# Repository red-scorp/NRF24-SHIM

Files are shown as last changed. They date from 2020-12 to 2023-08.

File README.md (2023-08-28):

# NRF24-SHIM project

NRF24-SHIM (mini-HAT), an interface board for NRF32L01+ radio boards for Raspberry Pi.

This project came to reality when I was looking for a way to connect standard NRF24L01+ module to my Pi.
I had found many tutorials explaining how to connect NRF24 modules to Pi but no ready made board or even proper schematics.
"Hmm... DIY!" I've told myself and here we are.

## NRF24-SHIM

Raspberry Pi 40-pin **NRF24-SHIM** mini-HAT.

Preview:

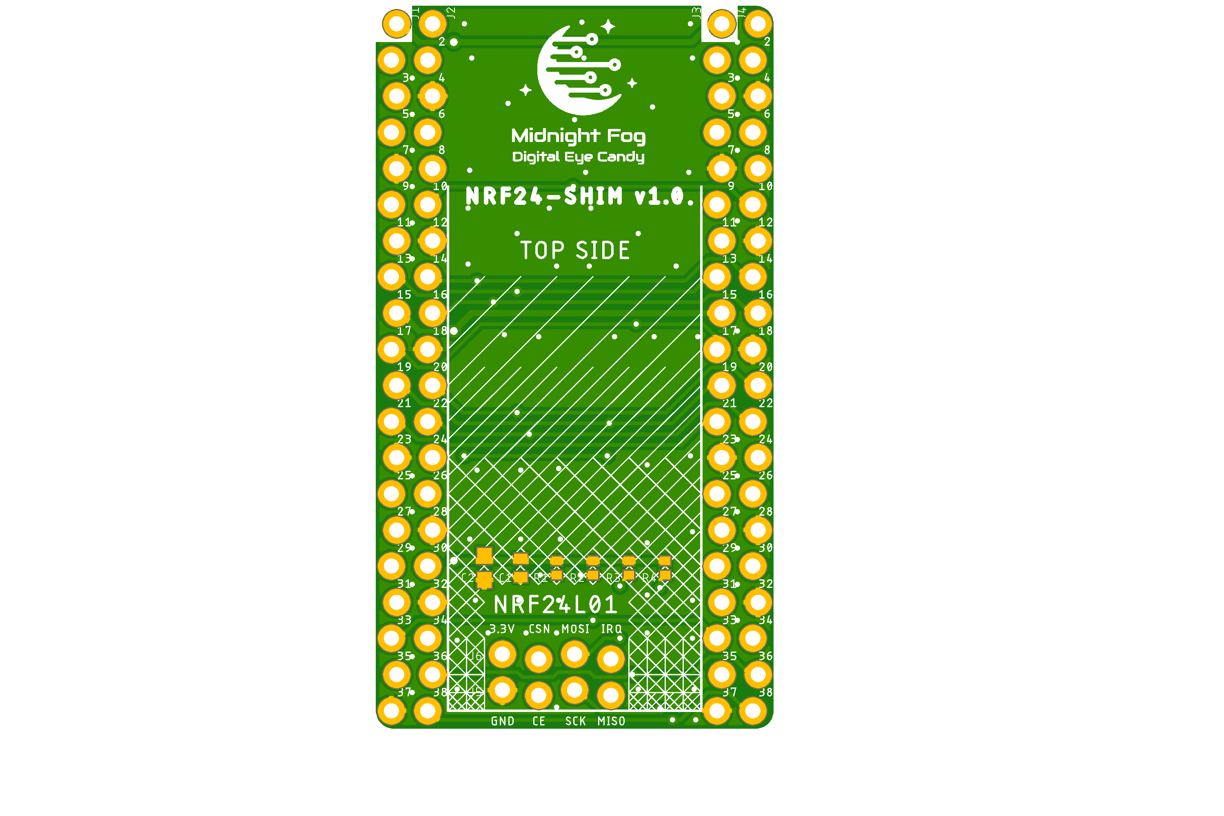
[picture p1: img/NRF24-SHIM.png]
NRF24-SHIM preview


[Schematics in PDF format](doc/NRF24-SHIM.pdf)

Features:

- locked Pi headers
- locked NRF24 headers
- double set of Pi headers (for inside and outside mount)
- SPI0/SPI1 bus selection
- CE/IRQ selection
- can be used as SHIM (no headers) or HAT (with headers)

Pins Configuration:

|NRF24 Pin |Option 1 |Option 2 |
|---|---|---|
|CE |GPIO22\* |GPIO25 |
|CSN |GPIO8\*  |GPIO18 |
|SCK |GPIO11\* |GPIO21 |
|MOSI |GPIO10\* |GPIO20 |
|MISO |GPIO9\*  |GPIO19 |
|IRQ |GPIO23 |GPIO24 |

\*) the pin is connected by default.

CAM files are available.

## NRF24-mini-SHIM

Raspberry Pi **NTF32-mini-SHIM** micro-HAT.

Preview:

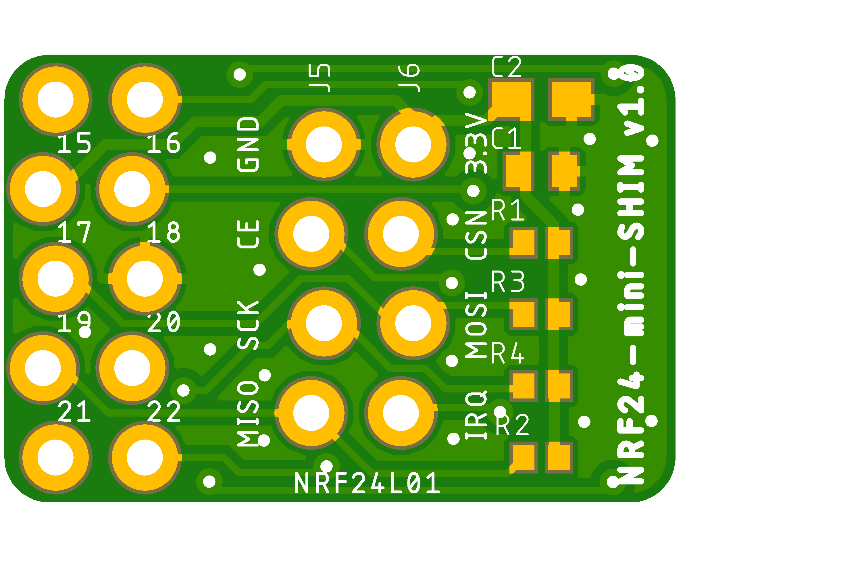
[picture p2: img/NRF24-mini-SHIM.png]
NRF24-mini-SHIM preview


[Schematics in PDF format](doc/NRF24-mini-SHIM.pdf)

Features:

- locked Pi headers
- locked NRF24 headers
- CE/IRQ selection
- very small size
- fits on 26- and 40-pin Pi headers

Pins Configuration:

|NRF24 Pin |Option 1 |Option 2 |
|---|---|---|
|CE |GPIO22\* |GPIO25 |
|CSN |GPIO8\*  | |
|SCK |GPIO11\* | |
|MOSI |GPIO10\* | |
|MISO |GPIO9\*  | |
|IRQ |GPIO23 |GPIO24 |

\*) the pin is connected by default.

CAM files are available.

## NRF24-zero-SHIM

Raspberry Pi zero 40-pin **NRF24-zero-SHIM** mini-HAT.

Preview:

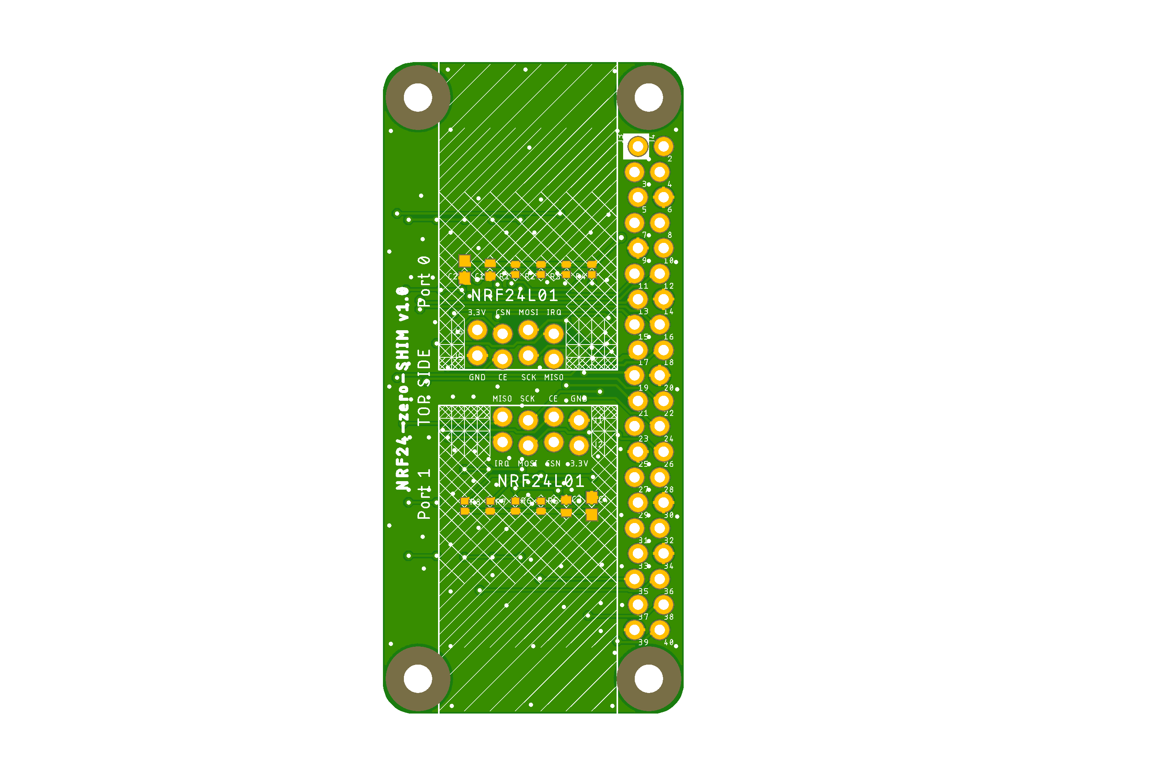
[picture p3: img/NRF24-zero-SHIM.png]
NRF24-zero-SHIM preview


[Schematics in PDF format](doc/NRF24-zero-SHIM.pdf)

Features:

- locked Pi headers
- locked NRF24 headers
- Pi zero board style
- SPI0/SPI1 bus selection
- CE/IRQ selection
- double NRF24 configuration possible
- can be used as SHIM (no headers) or HAT (with headers)

Pins Configuration:

|NRF24 Pin |Option 1 |Option 2 |Option 3 |Option 4 |Option 5 |
|---|---|---|---|---|---|
|P0 CE |GPIO22\* |GPIO25 |GPIO27 | | |
|P0 CSN |GPIO8\*  |GPIO7 |GPIO18 |GPIO17 |GPIO16 |
|P0 SCK |GPIO11\* |GPIO21 | | | |
|P0 MOSI |GPIO10\* |GPIO20 | | | |
|P0 MISO |GPIO9\*  |GPIO19 | | | |
|P0 IRQ |GPIO23 |GPIO24 | | | |
|P1 CE |GPIO22 |GPIO25\* |GPIO27 | | |
|P1 CSN |GPIO8 |GPIO7 |GPIO18\* |GPIO17 |GPIO16 |
|P1 SCK |GPIO11 |GPIO21\* | | | |
|P1 MOSI |GPIO10 |GPIO20\* | | | |
|P1 MISO |GPIO9 |GPIO19\* | | | |
|P1 IRQ |GPIO23 |GPIO24 | | | |

\*) the pin is connected by default.

CAM files are available.

## BOM

Bill Of Materials is currently available only for LCSC Electronic Components Distributor, which is probably cheapest anyway.

### LCSC BOM

|Designator |Part/Value |Package/Footprint |LCSC # |
|---|---|---|---|
|C1, C3\* |Cap. 100nF |0402 |C1525  |
|C2, C4\* |Cap. 1uF |0603 |C15849 |
|R1, R2, R3, R4, R5, R6, R7, R8\*|Res. 10K |0402 |C25744 |

\*) These passive components are optional but it's recommended to install them.

## Links

- [pinout.xyz](https://pinout.xyz/) - a brilliant resource on topic of Pi's pinout and HATs.
- [raspberrypi/hats](https://github.com/raspberrypi/hats) - Pi's HAT specification.
- [Communication between Arduino AND Raspberry Pi using NRF24L01](https://medium.com/@anujdev11/communication-between-arduino-and-raspberry-pi-using-nrf24l01-818687f7f363) - how to setup NRF24L01 with Pi.
- [Funkkommunikation zwischen Raspberry Pi’s und Arduinos (2.4 GHz)](https://tutorials-raspberrypi.de/funkkommunikation-zwischen-raspberry-pis-und-arduinos-2-4-ghz/) - how to setup NRF24L01 with Pi in German.
- [Connecting an nRF24L01+ to Raspberry Pi](https://www.hackster.io/wirekraken/connecting-an-nrf24l01-to-raspberry-pi-9c0a57) - one more setup example.

## How to help

Your contributions as code, resources, or finances are welcome! Please contact me directly via email at andriy.golovnya@gmail.com or through my [GitHub profile](https://github.com/red-scorp).

If you'd like to make a financial contribution, you can donate via [PayPal](http://paypal.me/redscorp) or [Ko-Fi](http://ko-fi.com/redscorp). Your support is greatly appreciated.

Thanks in advance!

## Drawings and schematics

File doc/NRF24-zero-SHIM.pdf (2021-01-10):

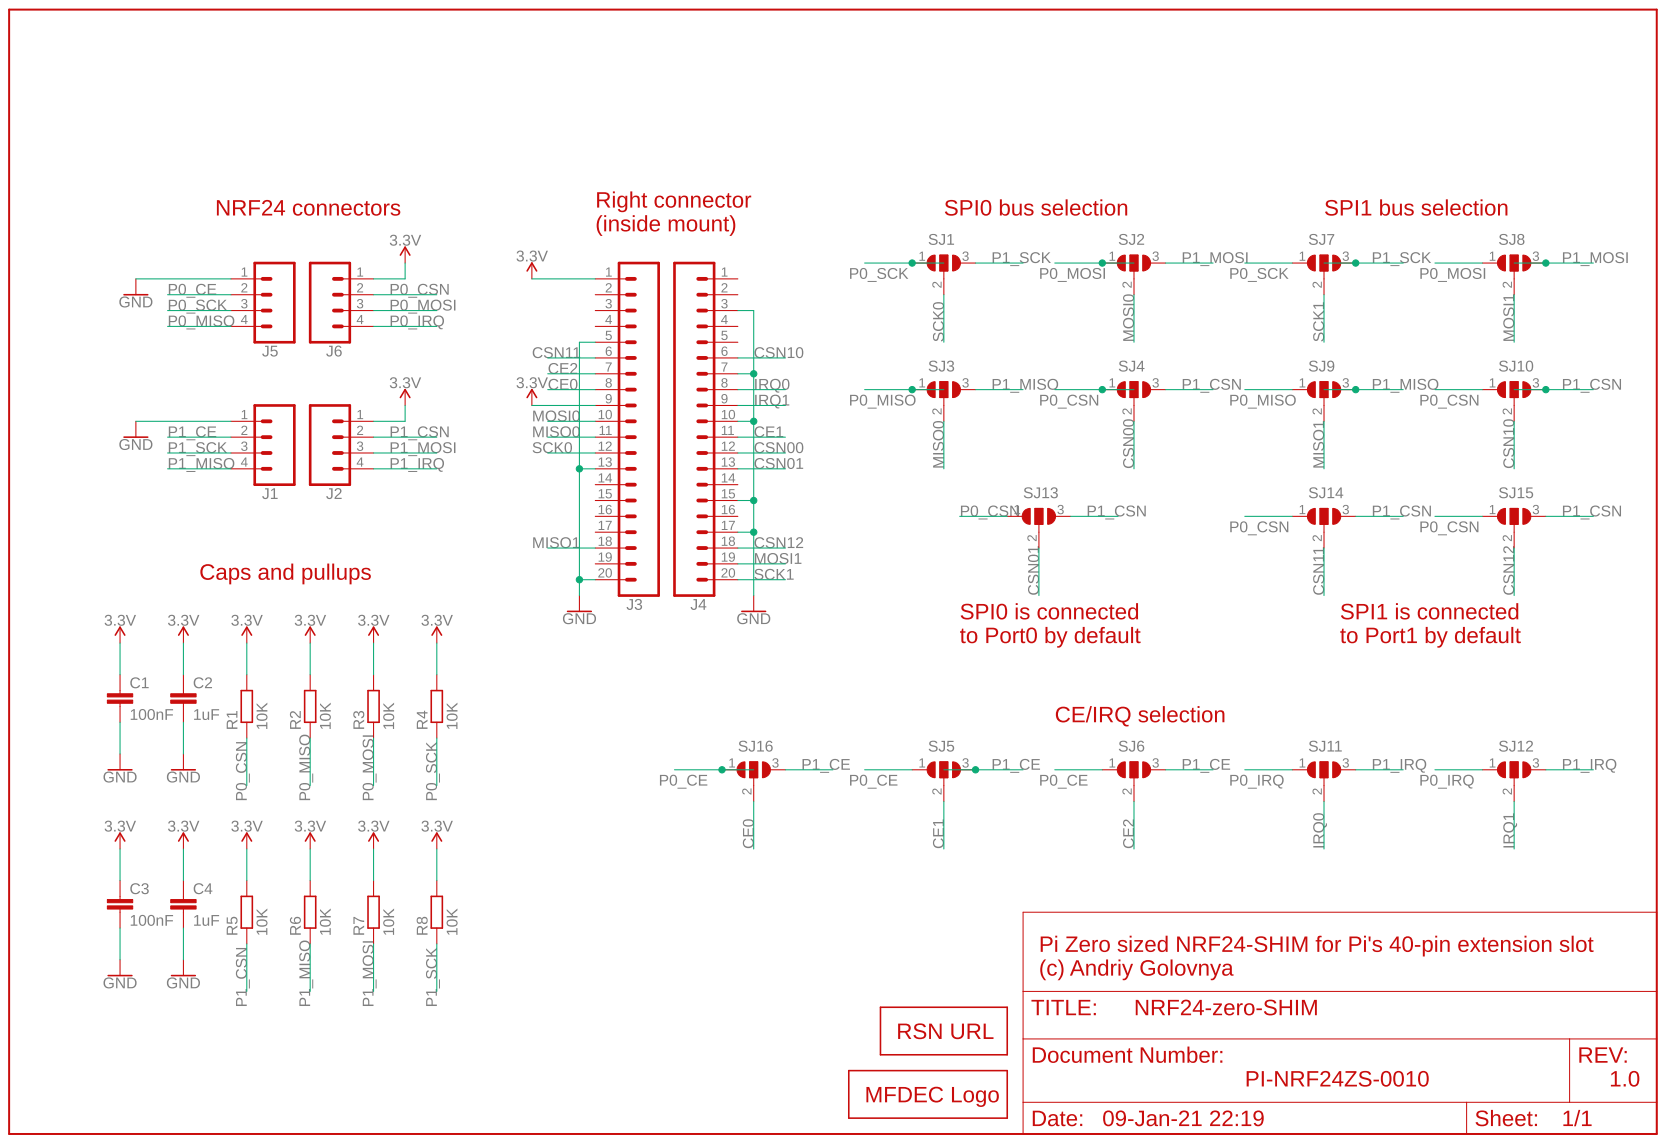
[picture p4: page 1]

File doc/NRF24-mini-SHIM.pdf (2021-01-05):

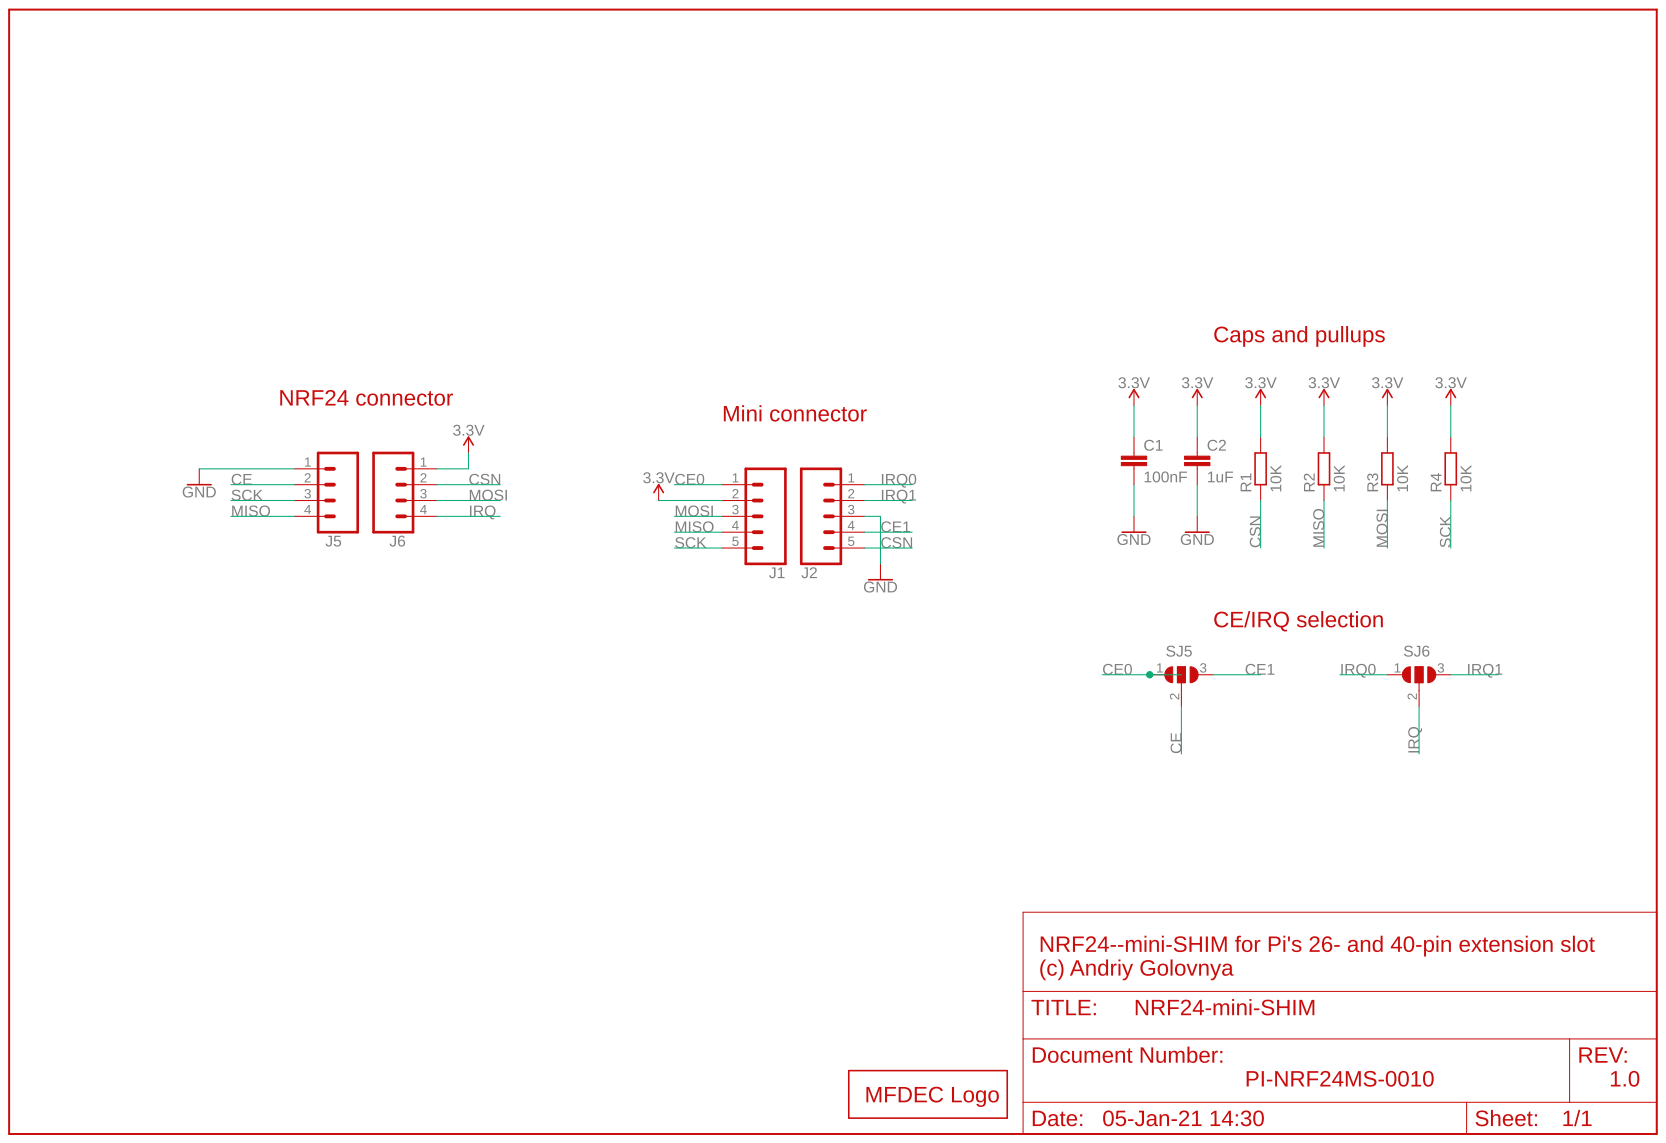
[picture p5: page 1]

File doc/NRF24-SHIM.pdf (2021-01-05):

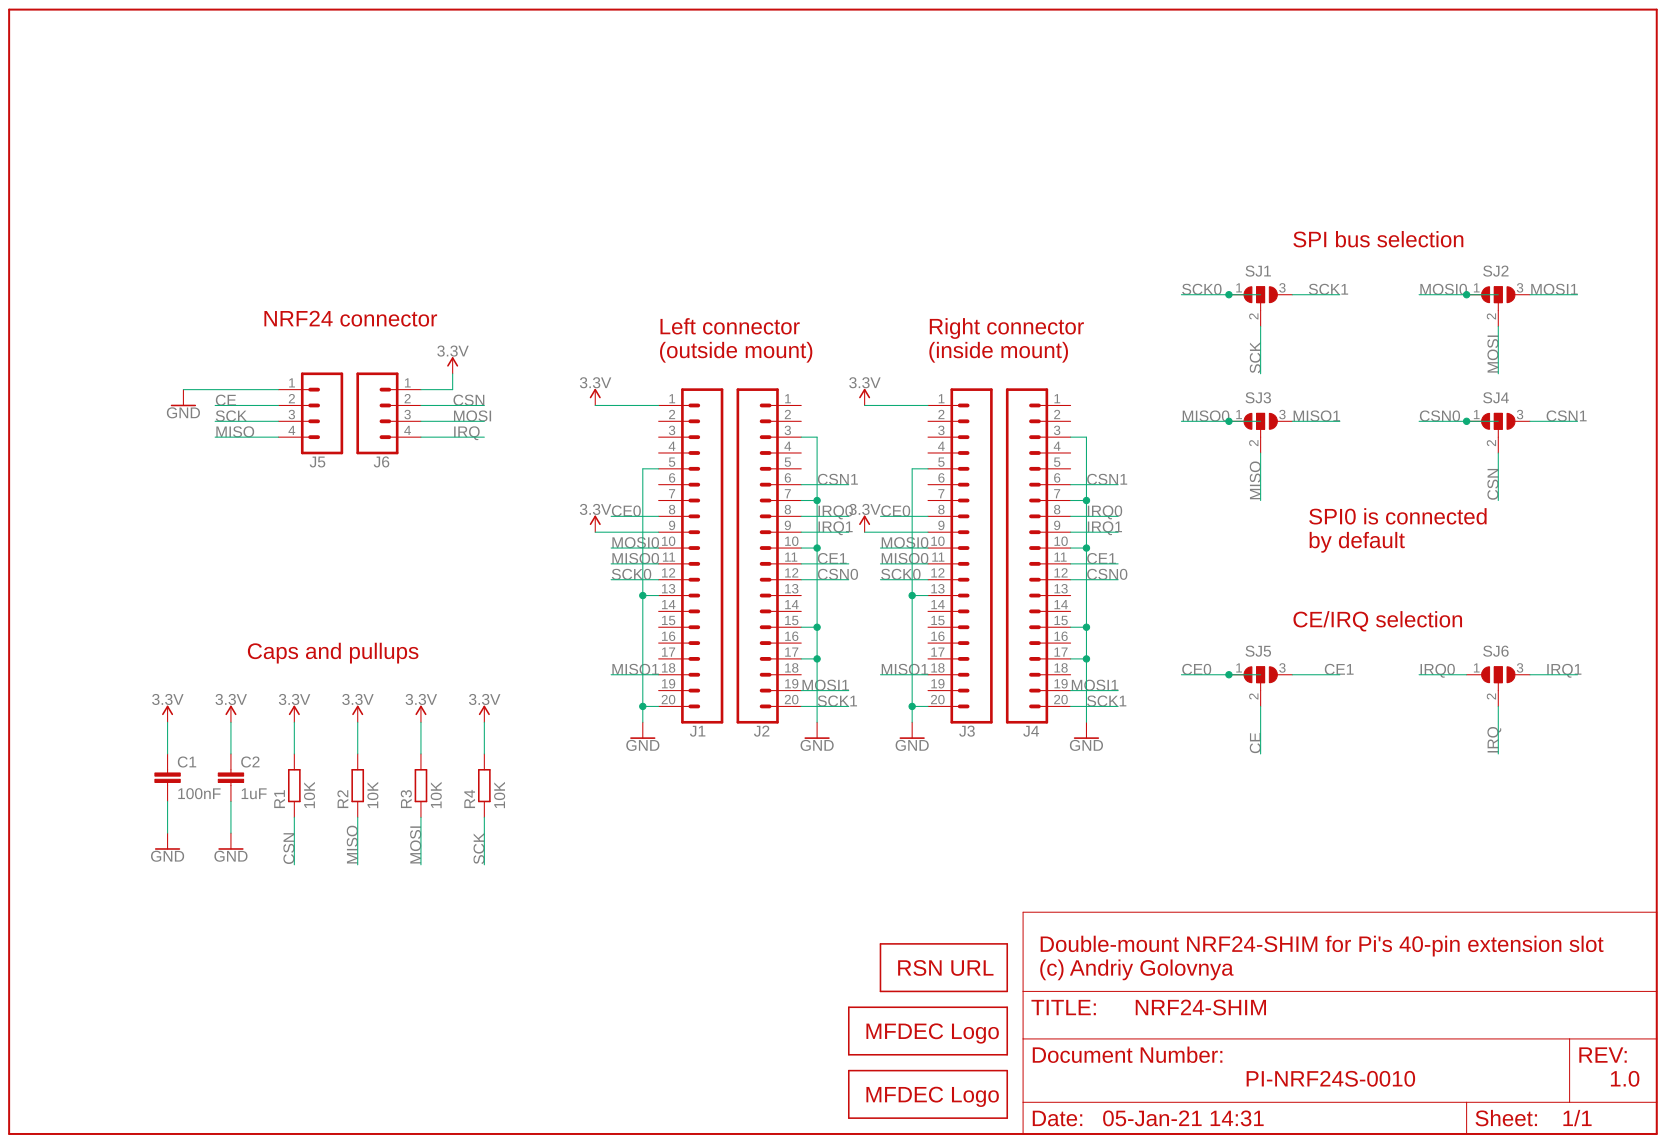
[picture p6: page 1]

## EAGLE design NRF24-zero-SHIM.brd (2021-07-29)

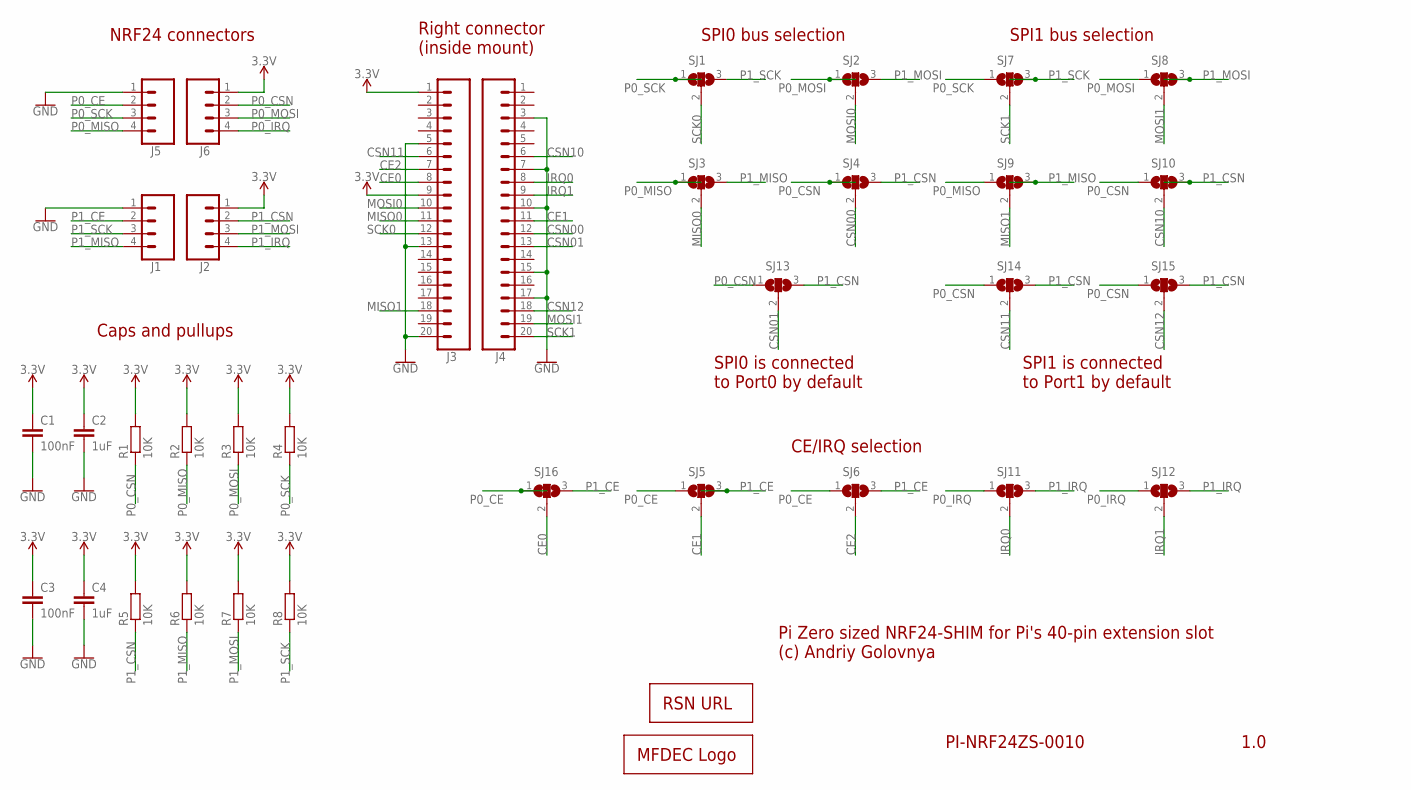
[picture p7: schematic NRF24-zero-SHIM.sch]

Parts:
C1, C3: 100nF; C0402
C2, C4: 1uF; C0603
J1, J2, J5, J6: CONN_04LOCK; 1X04_LOCK
J3, J4: CONN_20LOCK; 1X20_LOCK
LOGO1: MFDECLOGO_SQ_8MM; MFDEC_SQ_8MM
LOGO3: RSNURL_QR_10MM
R1, R2, R3, R4, R5, R6, R7, R8: 10K; R0402
SJ1, SJ2, SJ3, SJ4, SJ5, SJ6, SJ7, SJ8, SJ9, SJ10, SJ11, SJ12, SJ13, SJ14, SJ15, SJ16: SJ2; SJ_2

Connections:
3.3V: C1.1, C2.1, C3.1, C4.1, J2.1, J3.1, J3.9, J6.1, R1.2, R2.2, R3.2, R4.2, R5.2, R6.2, R7.2, R8.2
CE0: J3.8, SJ16.2
CE1: J4.11, SJ5.2
CE2: J3.7, SJ6.2
CSN00: J4.12, SJ4.2
CSN01: J4.13, SJ13.2
CSN10: J4.6, SJ10.2
CSN11: J3.6, SJ14.2
CSN12: J4.18, SJ15.2
GND: C1.2, C2.2, C3.2, C4.2, J1.1, J3.5, J3.13, J3.20, J4.3, J4.7, J4.10, J4.15, J4.17, J5.1
IRQ0: J4.8, SJ11.2
IRQ1: J4.9, SJ12.2
MISO0: J3.11, SJ3.2
MISO1: J3.18, SJ9.2
MOSI0: J3.10, SJ2.2
MOSI1: J4.19, SJ8.2
P0_CE: J5.2, SJ5.1, SJ6.1, SJ16.1
P0_CSN: J6.2, R1.1, SJ4.1, SJ10.1, SJ13.1, SJ14.1, SJ15.1
P0_IRQ: J6.4, SJ11.1, SJ12.1
P0_MISO: J5.4, R2.1, SJ3.1, SJ9.1
P0_MOSI: J6.3, R3.1, SJ2.1, SJ8.1
P0_SCK: J5.3, R4.1, SJ1.1, SJ7.1
P1_CE: J1.2, SJ5.3, SJ6.3, SJ16.3
P1_CSN: J2.2, R5.1, SJ4.3, SJ10.3, SJ13.3, SJ14.3, SJ15.3
P1_IRQ: J2.4, SJ11.3, SJ12.3
P1_MISO: J1.4, R6.1, SJ3.3, SJ9.3
P1_MOSI: J2.3, R7.1, SJ2.3, SJ8.3
P1_SCK: J1.3, R8.1, SJ1.3, SJ7.3
SCK0: J3.12, SJ1.2
SCK1: J4.20, SJ7.2

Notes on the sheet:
1.0
PI-NRF24ZS-0010
Pi Zero sized NRF24-SHIM for Pi's 40-pin extension slot (c) Andriy Golovnya
NRF24 connectors
Caps and pullups
Right connector (inside mount)
SPI0 bus selection
SPI0 is connected to Port0 by default
CE/IRQ selection
SPI1 bus selection
SPI1 is connected to Port1 by default

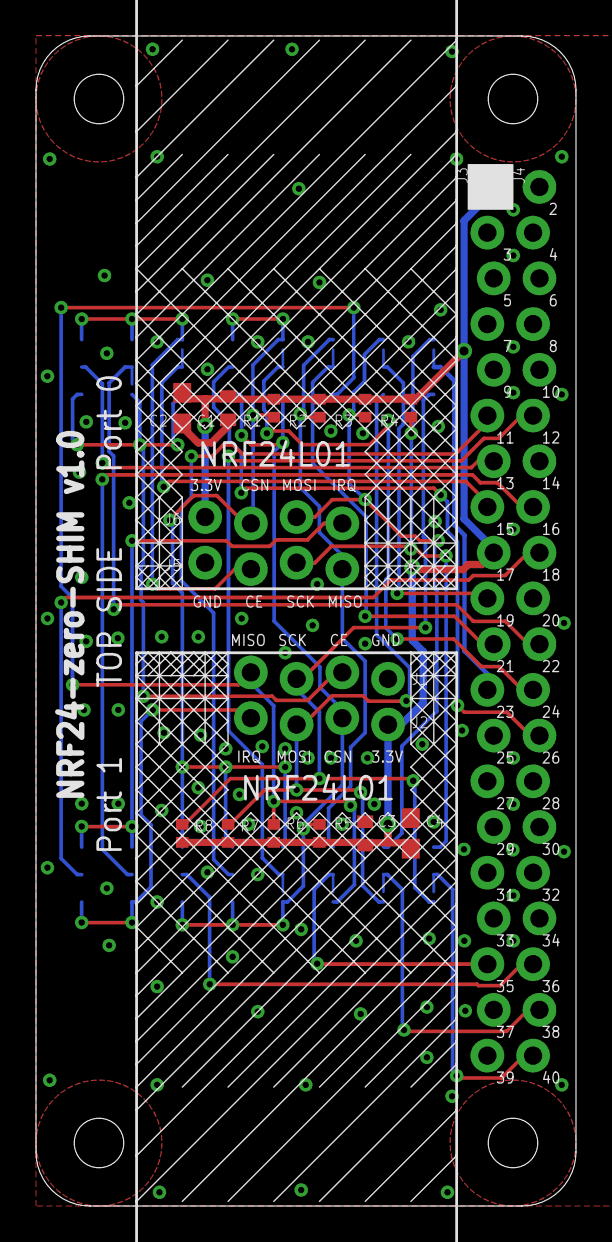
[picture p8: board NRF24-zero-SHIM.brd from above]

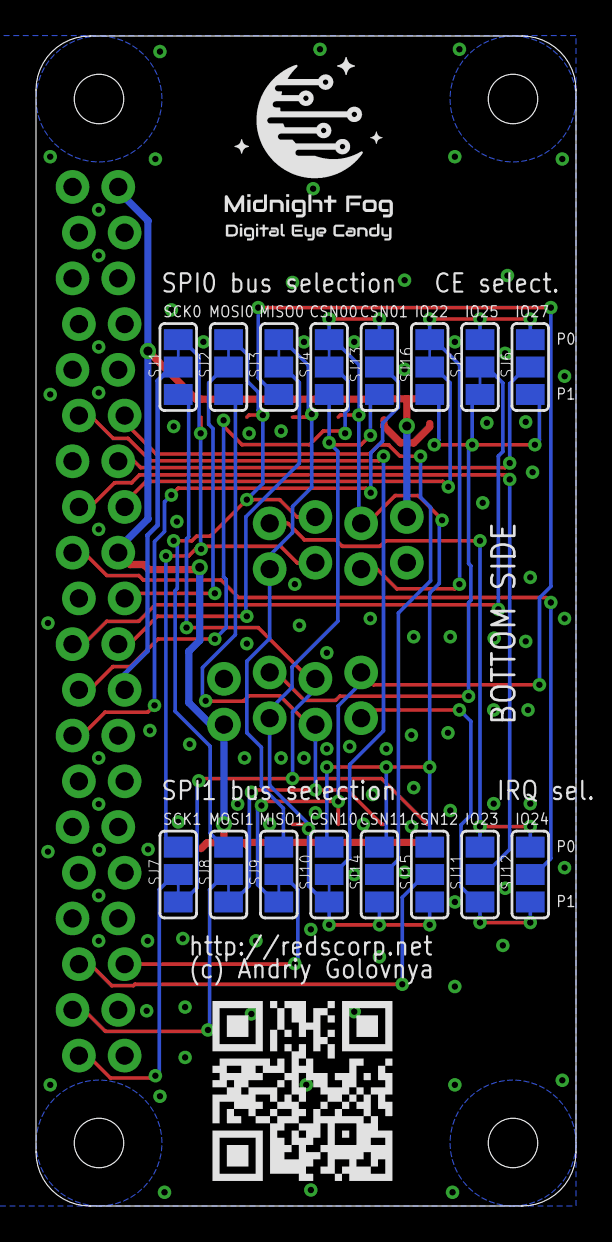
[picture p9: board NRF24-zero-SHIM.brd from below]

Board: 2 copper layers, 30.0 x 65.0 mm, 36 parts (18 on the bottom side), 30 nets.

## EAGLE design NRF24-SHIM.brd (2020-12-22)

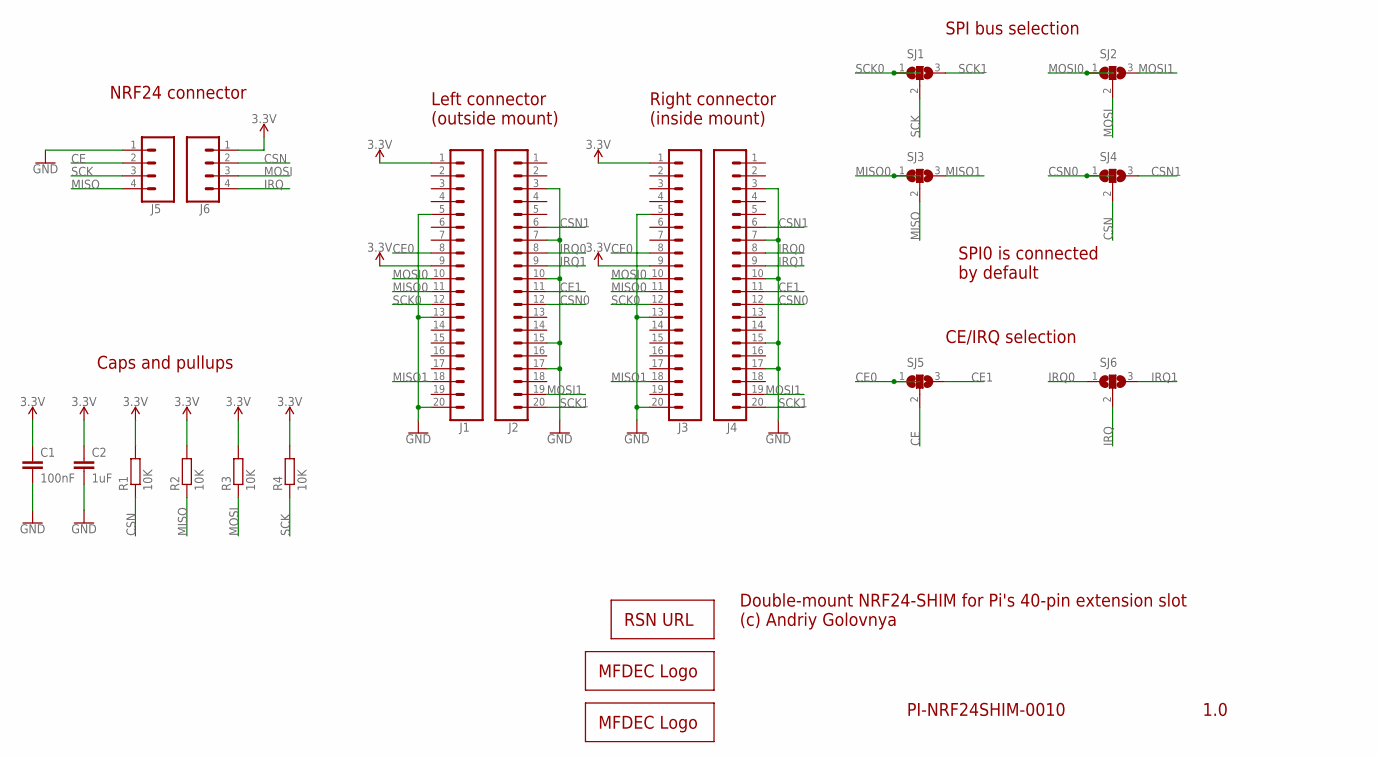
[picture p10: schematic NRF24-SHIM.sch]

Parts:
C1: 100nF; C0402
C2: 1uF; C0603
J1, J2, J3, J4: CONN_20LOCK; 1X20_LOCK
J5, J6: CONN_04LOCK; 1X04_LOCK
LOGO1: MFDECLOGO_SQ_8MM; MFDEC_SQ_8MM
LOGO2: MFDECLOGO_L_20MM; MFDEC_L_20MM
LOGO3: RSNURL_QR_10MM
R1, R2, R3, R4: 10K; R0402
SJ1, SJ2, SJ3, SJ4, SJ5, SJ6: SJ2; SJ_2

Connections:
3.3V: C1.1, C2.1, J1.1, J1.9, J3.1, J3.9, J6.1, R1.2, R2.2, R3.2, R4.2
CE: J5.2, SJ5.2
CE0: J1.8, J3.8, SJ5.1
CE1: J2.11, J4.11, SJ5.3
CSN: J6.2, R1.1, SJ4.2
CSN0: J2.12, J4.12, SJ4.1
CSN1: J2.6, J4.6, SJ4.3
GND: C1.2, C2.2, J1.5, J1.13, J1.20, J2.3, J2.7, J2.10, J2.15, J2.17, J3.5, J3.13, J3.20, J4.3, J4.7, J4.10, J4.15, J4.17, J5.1
IRQ: J6.4, SJ6.2
IRQ0: J2.8, J4.8, SJ6.1
IRQ1: J2.9, J4.9, SJ6.3
MISO: J5.4, R2.1, SJ3.2
MISO0: J1.11, J3.11, SJ3.1
MISO1: J1.18, J3.18, SJ3.3
MOSI: J6.3, R3.1, SJ2.2
MOSI0: J1.10, J3.10, SJ2.1
MOSI1: J2.19, J4.19, SJ2.3
SCK: J5.3, R4.1, SJ1.2
SCK0: J1.12, J3.12, SJ1.1
SCK1: J2.20, J4.20, SJ1.3

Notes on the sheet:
1.0
PI-NRF24SHIM-0010
Double-mount NRF24-SHIM for Pi's 40-pin extension slot (c) Andriy Golovnya
NRF24 connector
Caps and pullups
Left connector (outside mount)
Right connector (inside mount)
SPI bus selection
SPI0 is connected by default
CE/IRQ selection

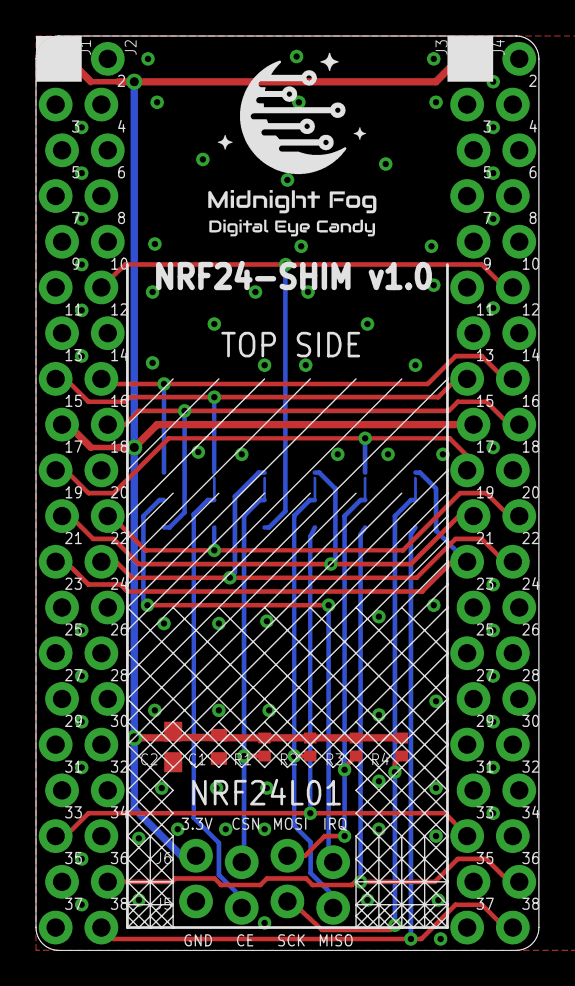
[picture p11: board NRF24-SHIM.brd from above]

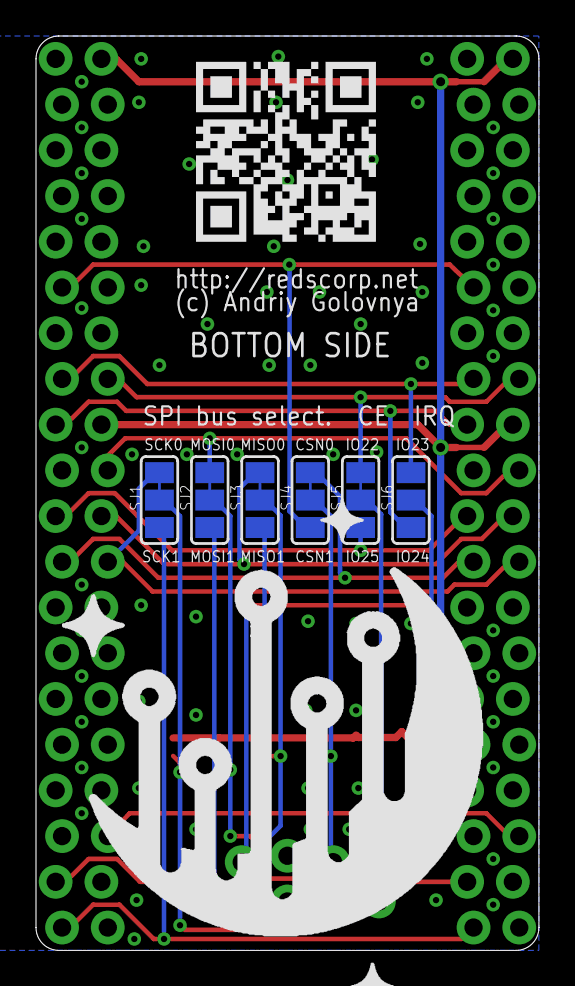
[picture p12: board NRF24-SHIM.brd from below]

Board: 2 copper layers, 27.9 x 50.8 mm, 21 parts (8 on the bottom side), 20 nets.

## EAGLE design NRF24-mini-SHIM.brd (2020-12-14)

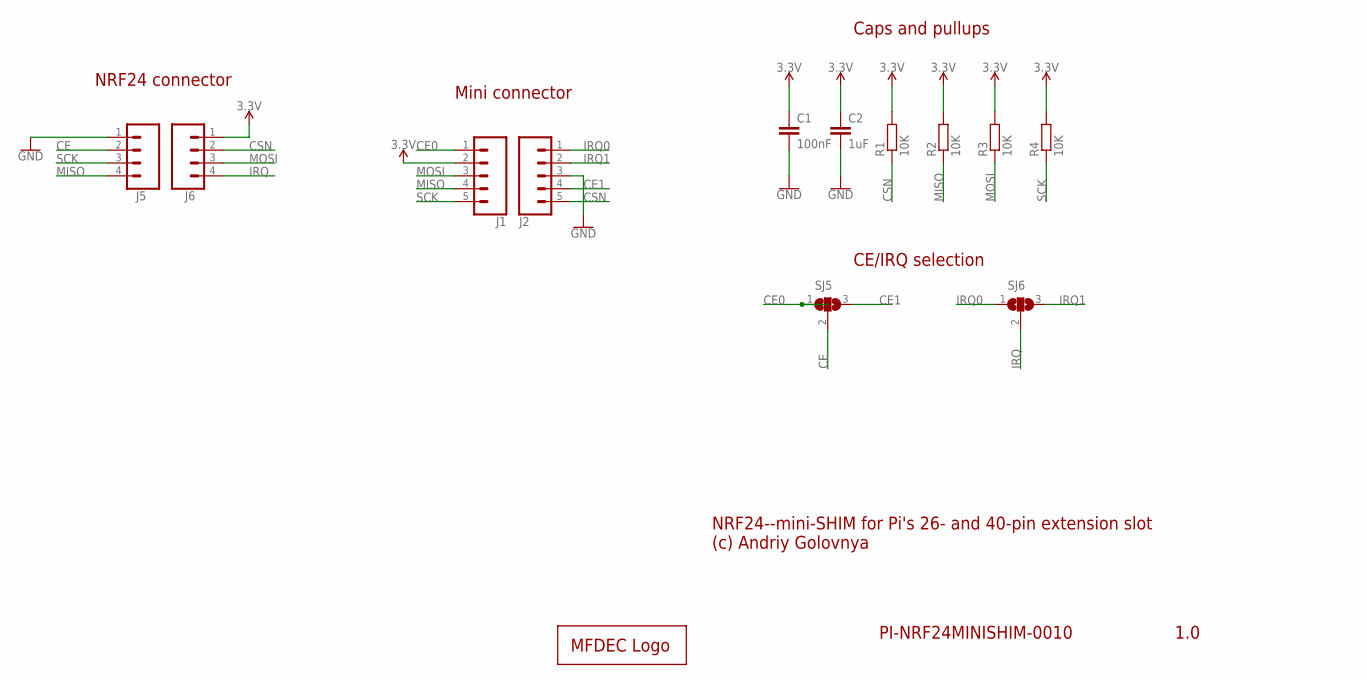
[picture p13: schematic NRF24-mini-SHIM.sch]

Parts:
C1: 100nF; C0402
C2: 1uF; C0603
J1, J2: CONN_05LOCK; 1X05_LOCK
J5, J6: CONN_04LOCK; 1X04_LOCK
LOGO1: MFDECLOGO_L_10MM; MFDEC_L_10MM
R1, R2, R3, R4: 10K; R0402
SJ5, SJ6: SJ2; SJ_2

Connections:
3.3V: C1.1, C2.1, J1.2, J6.1, R1.2, R2.2, R3.2, R4.2
CE: J5.2, SJ5.2
CE0: J1.1, SJ5.1
CE1: J2.4, SJ5.3
CSN: J2.5, J6.2, R1.1
GND: C1.2, C2.2, J2.3, J5.1
IRQ: J6.4, SJ6.2
IRQ0: J2.1, SJ6.1
IRQ1: J2.2, SJ6.3
MISO: J1.4, J5.4, R2.1
MOSI: J1.3, J6.3, R3.1
SCK: J1.5, J5.3, R4.1

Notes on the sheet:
1.0
PI-NRF24MINISHIM-0010
NRF24--mini-SHIM for Pi's 26- and 40-pin extension slot (c) Andriy Golovnya
NRF24 connector
Caps and pullups
Mini connector
CE/IRQ selection

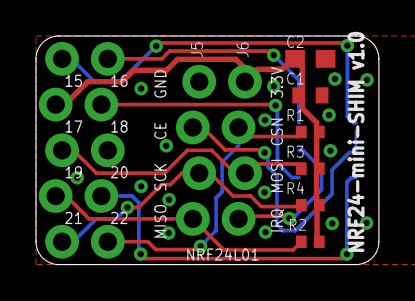
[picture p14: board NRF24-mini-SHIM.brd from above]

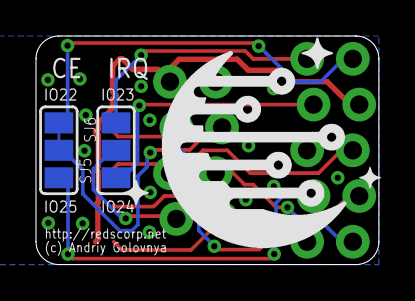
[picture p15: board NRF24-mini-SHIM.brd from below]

Board: 2 copper layers, 19.1 x 12.7 mm, 13 parts (3 on the bottom side), 12 nets.

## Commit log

2020-12-07 Initial board design
    [NRF24-SHIM.brd, NRF24-SHIM.sch]
2020-12-07 removed some unneeded stuff from the board.
    [NRF24-SHIM.brd]
2020-12-08 Add more pullups. Add more solder joints. Did some tracing.
    [NRF24-SHIM.brd, NRF24-SHIM.sch]
2020-12-09 Changed NRF24 connector to locked one. Moved passive components closer to the NRF24 connector. Add descriptive texts. Moved some stuff around.
    [NRF24-SHIM.brd, NRF24-SHIM.sch]
2020-12-10 Moved some traces around. Added some NRF24 location decoration.
    [NRF24-SHIM.brd, NRF24-SHIM.sch]
2020-12-11 Moved some traces around. Fixed schematics description.
    [NRF24-SHIM.brd, NRF24-SHIM.sch]
2020-12-11 Add schematics in PDF format.
2020-12-13 Use more locking pin headers. Moved some traces.
    [NRF24-SHIM.brd, NRF24-SHIM.sch]
2020-12-14 Made minor adjustments to traces and vias.
    [NRF24-SHIM.brd]
2020-12-14 Add NRF24-mini-SHIM board design.
    [NRF24-mini-SHIM.brd, NRF24-mini-SHIM.sch]
2020-12-14 Generated schematics in PDF.
2020-12-18 Generated new PNG board preview.
2020-12-22 Minor fix in traces path
    [NRF24-SHIM.brd]
2020-12-23 Initial prototype of NRF24-zero-SHIM.
    [NRF24-zero-SHIM.brd, NRF24-zero-SHIM.sch]
2020-12-23 Changed the way how solder joins are organized.
    [NRF24-zero-SHIM.brd, NRF24-zero-SHIM.sch]
2020-12-24 Added zero-sized board.
    [NRF24-zero-SHIM.brd, NRF24-zero-SHIM.sch]
2021-01-04 Moved some traces and vias to allow better ground surface. Generated new PNG preview. Generated new CAM.
    [NRF24-zero-SHIM.brd]
2021-01-04 Add Port 0 and Port 1 texts. Moved some texts around. Generated new PNG preview. Generated new CAM.
    [NRF24-zero-SHIM.brd]
2021-01-05 Simplified document names. Generated PDF schematics.
    [NRF24-SHIM.sch, NRF24-mini-SHIM.sch, NRF24-zero-SHIM.sch]
2021-01-10 Fixed document description.
    [NRF24-zero-SHIM.sch]
2021-01-10 Added link to raspberrypi/hats
2021-07-29 Make round cutouts in screwing area. Generated CAM files. Generated PNG previews.
    [NRF24-zero-SHIM.brd]

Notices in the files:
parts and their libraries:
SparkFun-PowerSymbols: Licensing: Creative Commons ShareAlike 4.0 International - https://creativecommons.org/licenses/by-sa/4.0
